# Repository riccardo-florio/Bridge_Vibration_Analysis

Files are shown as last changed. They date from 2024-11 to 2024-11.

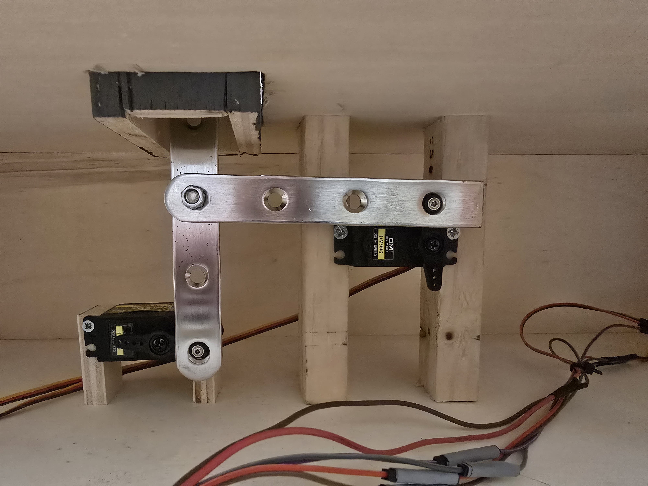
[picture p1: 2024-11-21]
viadotto/immagini e video/meccanismi interni.jpg

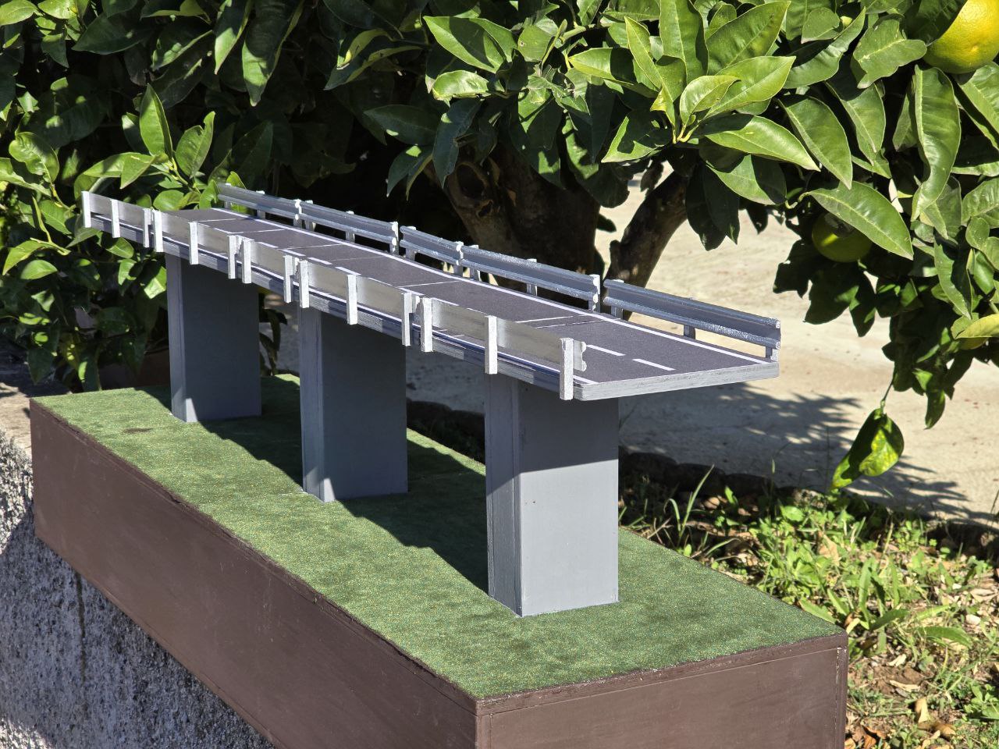
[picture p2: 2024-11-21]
viadotto/immagini e video/pnte completo.jpg

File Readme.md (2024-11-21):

# Bridge_Vibration_Analysis

Questo repository contiene i file e i documenti relativi al progetto di analisi delle vibrazioni di un modello in scala di un ponte. Il progetto è stato ideato per studiare i fenomeni di cedimento strutturale e vibrazioni sismiche, utilizzando sensori inerziali e un'applicazione per la raccolta e analisi dei dati. Condivido questo materiale per rendere il progetto replicabile e utile ad altri ricercatori, studenti e appassionati.

## Descrizione del progetto

Il progetto si basa su un modello in scala di un ponte progettato per simulare due scenari distinti:
1. L'abbassamento di uno o più piloni.
2. Vibrazioni indotte da terremoti.

### Struttura del repository

La repository è organizzata come segue:

- **/docs**: Contiene i documenti di riferimento che spiegano la teoria utilizzata per trasformare i dati dei sensori inerziali in angoli di rollio (roll), beccheggio (pitch) e imbardata (yaw). I documenti disponibili sono:
  - `Raccolta dati da smartphone.docx`: Spiega come raccogliere i dati dai sensori del telefono.
  - `Stima orientamento di un corpo.docx`: Illustra la teoria della stima dell'orientamento.

- **/viadotto**: Contiene i file specifici del modello in scala, suddivisi in sottocartelle:
  - **/codice_arduino**: Include il file `codice_arduino.ino`, fondamentale per il controllo del modello. In questo file sono presenti le variabili che consentono di regolare:
    - **L'abbassamento dei piloni**: *minVertical, maxVertical*.
    - **L'intensità del terremoto**: *minHorizontal, maxHorizontal*.
  - **/immagini e video**: File multimediali che mostrano il modello in funzione.
  - **/modelli 3D**: Contiene i file progettati con SketchUp:
    - `viadotto.skp`: Il modello 3D del ponte.
    - `viadotto abbassato.skp`: Una previsione del comportamento del ponte durante il cedimento di un pilone.
  - **/schema elettrico**: Include lo schema elettrico necessario per replicare il sistema:
    - `Schema elettrico ponte.dwg`
    - `Schema elettrico ponte.pdf`

- **Tesi Riccardo Florio.pdf**: La tesi completa, che documenta ogni aspetto del progetto.

## Obiettivi del progetto

Questo lavoro mira a fornire un sistema replicabile per analizzare le vibrazioni strutturali utilizzando un modello in scala di un ponte. La teoria utilizzata è ben documentata nei file contenuti in `/docs`, mentre le cartelle `/modelli 3D` e `/schema elettrico` offrono tutti i dettagli necessari per costruire il modello fisico. Il file `codice_arduino.ino` consente di controllare i fenomeni simulati, regolando con precisione l'abbassamento dei piloni e l'intensità delle vibrazioni.

## Come usare questo materiale

1. **Studio della teoria**: Inizia leggendo i documenti in `/docs` per comprendere come i dati dei sensori inerziali vengono trasformati in roll, pitch e yaw.
2. **Costruzione del modello**: Usa i file in `/modelli 3D` e `/schema elettrico` per costruire il modello in scala e configurare il sistema elettronico.
3. **Programmazione del modello**: Carica il file `codice_arduino.ino` sulla scheda Arduino Uno e regola le variabili per adattare il comportamento del modello alle tue esigenze.
4. **Simulazione**: Utilizza il modello per simulare scenari di cedimento strutturale e vibrazioni sismiche, raccogliendo dati per analisi successive.

## Licenza

Il materiale condiviso in questa repository è rilasciato con una licenza open-source, consentendo a chiunque di utilizzare, modificare e distribuire i contenuti, con l'obiettivo di promuovere la collaborazione e la condivisione della conoscenza.

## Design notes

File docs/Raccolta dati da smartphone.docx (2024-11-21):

## Introduzione

In questo documento spiego come convertire i dati ricevuti dai sensori inerziali in dati di roll pitch e yaw usando le formule spiegate in “Stima orientamento di un corpo.docx”. Quello che spiego qui è alla base del progetto Sensors To RPY Client (https://github.com/riccardo-florio/Sensors_To_RPY_Client).

## Strumenti utilizzati

App: ServerSensor

Link: https://github.com/umer0586/SensorServer

Altri riferimenti:

- Script python per comunicare con l’app: https://stackoverflow.com/questions/68127440/how-do-i-transmit-real-time-android-sensor-data-to-a-pc-wirelessly
- Per creare l’ambiente virtuale in python: https://www.youtube.com/watch?v=S6LMNLKhaEM&t=470s
- Libreria web: https://github.com/websocket-client/websocket-client

Versione Python: 3.11.3

Editor: PyCharm 2022.2.1

## Procedimento

Innanzitutto, dopo aver installato l’applicazione ServerSensor sul cellulare, ho creato la cartella "sersor_client", l’ho aperta con l’editor e ho creato ed attivato un ambiente virtuale. Quindi, ho selezionato l’interpreter python desiderato (quello della versione 3.11.1).

I dati dei sensori estratti dall’applicazione vengono trasmessi mediante il protocollo WebSocket sotto forma di file json.

In prima istanza creiamo un semplice script python che riceve e mostra a video i dati estratti: uso il codice specificato nella documentazione all’interno nel file "main.py"

Si noti che, affinché tutto funzioni correttamente, deve essere installata la libreria "websocket-client".

Quando tutto funziona, procedo col ricavare le rotazioni di Roll – Pitch – Yaw a partire dai dati estratti dai sensori del cellulare. Un primo codice per estrarre dati di roll e pitch sfruttando l’accelerometro è il seguente:

import websocket
import json
import math

# IP del dispositivo connesso
device_ip = "ws://192.168.1.75:8080"
# Inizializzazione di RPY
roll, pitch, yaw = 0, 0, 0
# Campo magnetico di riferimento

def on_message(ws, message):
# Estrazione dei dati inviati dallo smartphone
values = json.loads(message)['values']
type = json.loads(message)['type']

# Estraggo roll e pitch dall'accelerometro
global roll, pitch, yaw
if type == 'android.sensor.accelerometer':
a_sx = values[0]
a_sy = values[1]
a_sz = values[2]
roll = math.atan2(a_sy, a_sz)
pitch = math.atan2(a_sx, math.sqrt(pow(a_sy, 2) + pow(a_sz, 2)))

if type == 'android.sensor.magnetic_field':
pass

print("roll = ", roll, "pitch = ", pitch, "yaw = ", yaw)


def on_error(ws, error):
print("error occurred")
print(error)


def on_close(ws, close_code, reason):
print("connection close")
print("close code : ", close_code)
print("reason : ", reason)


def on_open(ws):
print("connected")


def connect(url):
ws = websocket.WebSocketApp(url,
on_open=on_open,
on_message=on_message,
on_error=on_error,
on_close=on_close)

ws.run_forever()


connect(device_ip + '/sensors/connect?types=[' +
'"android.sensor.accelerometer",' +
'"android.sensor.gyroscope",' +
'"android.sensor.magnetic_field"]')

Per ricavare pitch dobbiamo sfruttare il magnetometro. Oltre ai dati da esso estratti, sono necessari i dati del sistema di riferimento globale. Li ricaviamo dal sito indicato di seguito inserendo latitudine e longitudine della zona in cui si trova il sensore, oppure inserendo il cap.

https://www.ngdc.noaa.gov/geomag/calculators/magcalc.shtml#igrfwmm

Ottenuti i dati dell’ENU, li converto in microtesla e li memorizzo:

A questo punto applico le formule e calcolo YAW:

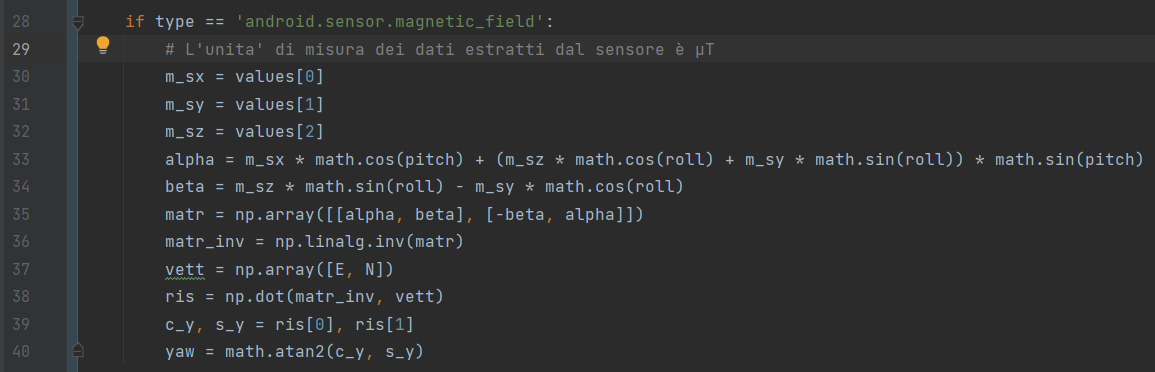
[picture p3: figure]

## Grafico real – time di RPY

Per questo scopo usiamo la libreria "matplotlib". Implementiamo un meccanismo per cui ogni secondo viene aggiornato il grafico con i nuovi valori rilevati dai sensori. Il problema incontrato in questa fase è che, per poter rilevare i dati dai sensori e contemporaneamente graficarli, bisogna eseguire due funzioni, "connect(…)" e "plt.show", in maniera concorrente. Eseguiamo la prima in un thread separato da quello principale.

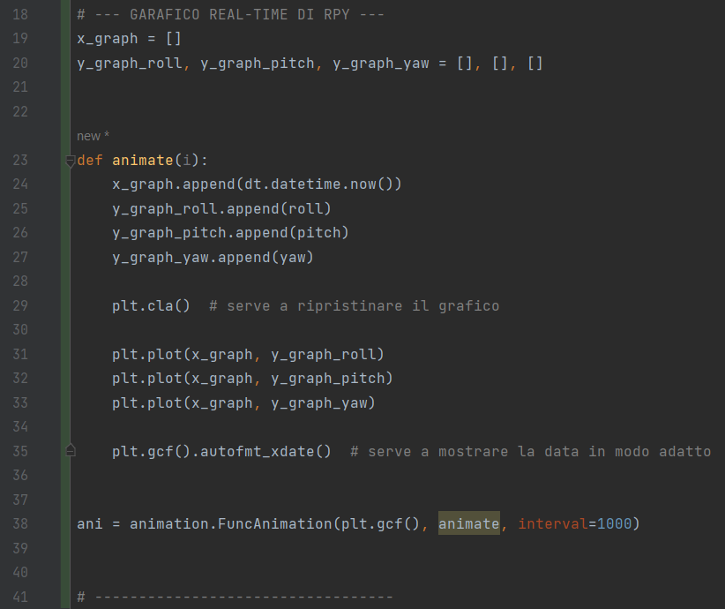
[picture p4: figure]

Di seguito, il codice per eseguire il rilevamento dei dati in un thread secondario:

## Applicazione del filtro

A questo punto possiamo notare come i dati dei sensori siano abbastanza rumorosi. Possiamo filtrarli con il seguente filtro passa – basso:

r(k)=α⋅r(k-1)+(1-α)⋅r_(acc) (k)

Dove:

- r(k) è il valore filtrato al tempo k
- r(k-1) è il valore filtrato al tempo precedente.
- r_(acc) (k) è il valore attuale del segnale (ad esempio, roll, pitch o yaw).
- α è un coefficiente che determina il grado di smussamento.

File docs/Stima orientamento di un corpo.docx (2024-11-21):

## Stima dell’orientamento di un dispositivo

(Fonte: materiale Professore)

L’orientamento di un corpo rigido può essere definito sia nello spazio tridimensionale, ovvero in R^3 , che su un piano bidimensionale, ovvero in R^2 .

Due corpi possono condividere la stessa posizione ma differire nell’orientamento; pertanto, è fondamentale comprendere come valutare l’orientamento di un corpo per determinarne lo stato.

### Stima dell’orientamento

Per stimare l’orientamento di un corpo sul piano, è richiesta una variabile reale θ∈R .

Per stimare l’orientamento di un corpo nello spazio, invece, sono necessarie tre variabili a valori reali ϕ∈R, ψ∈R, θ∈R .

Ci concentreremo, nel seguito, sull’orientamento in R^3

In particolare, è possibile raggiungere qualsiasi orientamento target partendo da un orientamento di riferimento noto, mediante l’applicazione di una sequenza specifica di rotazioni, le cui grandezze sono gli angoli di rotazione dell’orientamento del target.

3 angoli opportunamente scelti definiscono in modo inequivocabile l’atteggiamento di un corpo, ma dato un corpo, ci sono diversi gruppi di 3 angoli (opportunamente scelti) che ne definiscono l’orientamento.

### Orientamento di un corpo

Da un punto di vista generale, definire l’orientamento di un corpo implica stabilire l’orientamento di un sistema di riferimento attaccato al corpo {O’, x’, y’, z’} in relazione a un sistema di riferimento di interesse {O, x, y, z}

Da un punto di vista formale, ci sono tre modi principali per definire l’orientamento di un corpo:

- Matrici di rotazione
- Angoli di Eulero
- Quaternioni

Scegliere il formalismo appropriato rappresenta uno dei task principali in un sistema di posizionamento.

#### Matrici di rotazione

Le matrici rotazionali, spesso denominate matrici direzione coseno (DCMs), descrivono come un sistema di riferimento attaccato al corpo è orientato rispetto a un altro sistema di riferimento di interesse, in R^3 o in R^2 .

Funzionamento in R^2

Consideriamo due sistemi di riferimento A={O, x,y,z} e B={O, x^(') ,y^(') ,z^(') } , entrambi centrati nello stesso punto, ma con il secondo ruotato di un angolo α rispetto al primo.

Sia P un punto espresso come P_1 =(p_x , p_y ) in riferimento ad A e come P_2 =(p^(') _x , p^(') _y ) in riferimento a B.

Il punto P2 può essere referenziato rispetto al sistema di riferimento A:

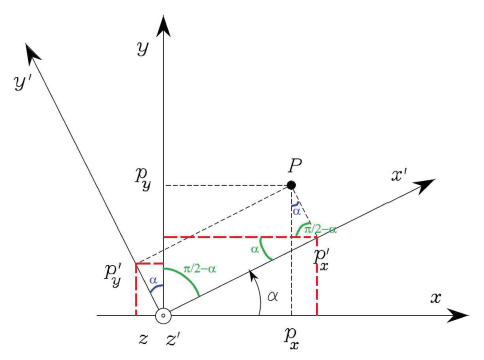
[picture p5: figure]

Ovvero:
p_x =p_x^(') cosα-p_y^(') sinα p_y =p_x^(') sinα+p_y^(') cosα
In forma matriciale:
P_1 =[cosα, -sinαsinα, cosα]
Matrice di rotazione:
R(α)=RB→A=[cosα, -sinαsinα, cosα] (ruota un punto in B in un punto in A)
Proprietà di R(α) :

1) RA→B=R^(-1) B→A=R^T B→A , cioè RA→B è una matrice ortogonale
2) R(-α)=R^T (α)
3) det{R(α)}=1
4) Le colonne di R(α) sono i versori che definiscono una base per B, espressa nel sistema di riferimento A. In altre parole, R(α) è una matrice di cambiamento di base, da B ad A.
5) R(α(t))=α(t)[0, -11, 0]R(α(t))

Funzionamento in R^n

Una matrice di rotazione R è tale che R∈SO(n) , dove SO(n) è il particolare gruppo ortogonale di matrici reali in R^(n×n) , cioè:

SO(n)={M∈R^(n×n) t.c. MM^T =M^T M=I_n ∧det{M}=1}

Proprietà:

1) RA→B=R^(-1) B→A=R^T B→A
2) det{R}=1
3) Ogni matrice R∈SO(n) è una matrice dei coseni direttori (vedi più avanti)
4) A causa del vincolo RR^T =R^T R=I_n , nonostante R abbia n^2 voci, solo (n(n-1))/2 parametri liberi sono ammessi; le n^2 voci sono funzioni di tali parametri liberi. In particolare: n=2→1 parametro libero n=3→3 parametri liberi
5) R(t)=A(t)R(t) , dove A(t)∈R^(n×n) è tale che A(t)+A^T (t)=0_(n×n) , cioè A(t) è una matrice antisimmetrica (vedi dopo).
6) R(t)=Φ[t,t_0 ]R(t_0 ) , dove Φ[t,t_0 ]∈R^(3×3) è una funzione tempo – variante. Inoltre, se R(t) è una rotazione tempo – variante con velocità costante, allora:

R(t)=e^(A(t-t_0 )) R(t_0 )

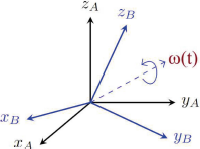
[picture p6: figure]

7) Considerando due sistemi di riferimento: A fisso e B che ruota intorno ad A con velocità ω(t)∈R^3 , dove:
  a. (ω(t))/(‖ω(t)‖) è l’asse di rotazione
  b. ‖ω(t)‖ è la velocità di rotazione attorno a ω(t)
  c. ω_A (t) e ω_B (t) definiscono ω(t) in A e in B rispettivamente

Allora, saranno soddisfatte le seguenti relazioni:

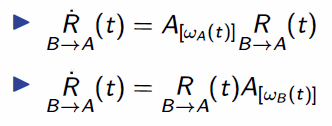
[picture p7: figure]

Ricorda queste ultime formule perché serviranno nello studio dei quaternioni in relazione alla velocità angolare.

L’operatore antisimmetrico

Analizziamo il caso di n=3

Sia v∈R^3 =[v_x ,v_y ,v_z ]^T , allora l’operatore antisimmetrico è A_([v]) , definito come:

L’operatore antisimmetrico rappresenta un prodotto incrociato:

Rotazione e traslazione

Consideriamo due sistemi di riferimento:

- A = {O_A ,x_A ,y_A ,z_A }
- B = {O_B ,x_B ,y_B ,z_B }

In cui O_B è rappresentato dal vettore t∈R^3 nel sistema di riferimento A.

Un punto P∈R^3 in A si indica con:

P_A =RB→AP_B +t

Oppure, in forma matriciale:

[, P_A , 1]=[RB→A, t0_3^T , 1][, P_B , 1]=R_t B→A[, P_B , 1]

R_t B→A∈R^(4×4) è una matrice di trasformazione e R_t B→A^(-1) =[RB→A^T , -RB→A^T t0_3^T , 1]

Matrice dei coseni direttori

(Fonte: D. Titterton, J. Weston, Strapdown Inertial Navigation Technology, Peter Peregrinus Ltd, 1997) (Ho praticamente copiato il paragrafo dal libro)

Un generico vettore V, riferito ad una terna cartesiana (a) di assi x, y, z, può essere definito come la somma di tre vettori:

V_a = V_x + V_y + V_z = V_x i + V_y j + V_z k

dove ciascuno dei termini rappresenta il vettore ottenuto proiettando V_a sugli assi della terna (a) di versori i, j, k.

Lo stesso vettore, riferito ad una seconda terna (b) avente la stessa origine e di assi x', y', z', può essere rappresentato in modo analogo dall'espressione:

V_b = V_(x^(')) + V_(y^(')) + V_(z^(')) = V_(x^(')) i^(') + V_(y^(')) j^(') + V_(z^(')) k^(')

dove ciascuno dei tre termini può essere ottenuto proiettando V_x , V_y , V_z rispettivamente sugli assi x', y', z' della terna (b) di versori i', j', k'.

Si ha pertanto:

V_(x^(')) = [V_x cos(x^(') ,x); V_y cos(x^(') ,y); V_z cos(x^(') ,z)]

V_(y^(')) = [V_x cos(y^(') ,x); V_y cos(y^(') ,y); V_z cos(y^(') ,z)]

V_(z^(')) = [V_x cos(z^(') ,x); V_y cos(z^(') ,y); V_z cos(z^(') ,z)]

dove, per esempio, cos(x^(') ,y) rappresenta il coseno dell'angolo che l'asse x' della terna (b) forma con l'asse y della terna (a) ed è indicato come coseno direttore.

Si può anche scrivere:

V_(x^(')) = [C_11 V_x ; C_12 V_y ; C_13 V_z ]

V_(y^(')) = [C_21 V_x ; C_22 V_y ; C_23 V_z ]

V_(z^(')) = [C_31 V_x ; C_32 V_y ; C_33 V_z ]

o, più sinteticamente:

V_b = C_a^b V_a

dove C_a^b è la matrice dei cosenti direttori che ci permette di passare dalla terna (a) alla terna (b):

C_a^b =(C_11 , C_12 , C_13 C_21 , C_22 , C_23 C_31 , C_32 , C_33 )

L'elemento C_(ij) della matrice C_a^b rappresenta, quindi, il coseno che l'asse i della terna (b) forma con l'asse j della terna (a).

Il passaggio da una terna all'altra può avvenire anche attraverso una o più terne intermedie come, ad esempio:

V_b = C_c^b C_a^c V_a

Il prodotto delle matrici non è commutativo, pertanto:

C_c^b C_a^c ≠ C_a^c C_c^b

Se le due terne sono ortogonali, l'inversa della matrice è uguale alla sua trasposta e si ha:

C_a^b = (C_a^b )^(-1) = (C_a^b )^T

avendo indicato con l'apice T la trasposta.

La stessa matrice può anche essere ottenuta tenendo presente che è possibile passare dalla terna (a) alla terna (b) mediante tre successive rotazioni θ_1 ,θ_2 ,θ_3 rispetto a ciascun asse.

Per esempio, la rotazione intorno all’asse z di un angolo θ_3 , indicata con R_z (θ_3 ) , lascia invariata la direzione dell’asse z mentre gli assi x, y (e quindi i versori i, j) ruotano di un angolo θ_3 . Si ha, per la relazione x^(') =cos(θ)x +sin(θ)(e×x) , che:

i_1 =cosθ_3 i+sinθ_3 j

j_1 =-sinθ_3 i+cosθ_3 j

k_1 =k

O più sinteticamente

(i_1 j_1 k_1 )=(cosθ_3 , sinθ_3 , 0-sinθ_3 , cosθ_3 , 00, 0, 1)(ijk)

Pertanto:

R_z (θ_3 )=(cosθ_3 , sinθ_3 , 0-sinθ_3 , cosθ_3 , 00, 0, 1)

Analogamente, una rotazione di un angolo θ_1 intorno all’asse x ed una rotazione di un angolo θ_2 intorno all’asse y si possono rappresentare rispettivamente con le matrici:

R_x (θ_1 )=(1, 0, 00, cosθ_1 , sinθ_1 0, -sinθ_1 , cosθ_1 ) R_y (θ_2 )=(cosθ_2 , 0, -sinθ_2 0, 1, 0sinθ_2 , 0, cosθ_2 )

Gli angoli θ_1 ,θ_2 ,θ_3 vengono detti angoli di Eulero.

La matrice dei coseni direttori C_a^b può ricavarsi effettuando il prodotto delle tre matrici ora definite nell’ipotesi di conoscere gli angoli di rotazione e la successione di essi in quanto il prodotto delle matrici non è commutativo.

(Fine matrice dei coseni direttori – libro “Navigazione inerziale e integrata”)

#### Angoli di Eulero

Immaginiamo di prendere il frame (= sistema di riferimento) A in mano e di ruotarlo finché non appare proprio come il frame B. Il teorema di rotazione di Eulero afferma che qualsiasi rotazione può essere considerata come una sequenza di rotazioni attorno a diversi assi di coordinate.

Teorema di rotazione di Eulero

Due sistemi di coordinate ortonormali indipendenti possono essere collegati da una sequenza di rotazioni (non più di tre) attorno agli assi di coordinate, dove non ci possono essere due rotazioni successive attorno allo stesso asse.

Rotazioni elementari (standard)

Una rotazione elementare è una rotazione intorno ad un asse (x, y o z) che coinvolge solo un angolo, cioè l’angolo di rotazione attorno all’asse scelto.

- Rotazione attorno all’asse x (primo asse): R_x (θ_1 )=(1, 0, 00, cosθ_1 , sinθ_1 0, -sinθ_1 , cosθ_1 )
- Rotazione attorno all’asse y (secondo asse): R_y (θ_2 )=(cosθ_2 , 0, -sinθ_2 0, 1, 0sinθ_2 , 0, cosθ_2 )
- Rotazione attorno all’asse z (terzo asse): R_z (θ_3 )=(cosθ_3 , sinθ_3 , 0-sinθ_3 , cosθ_3 , 00, 0, 1)

Una generica matrice di rotazione può essere ottenuta componendo un'opportuna sequenza di tre rotazioni elementari, garantendo che non vengano effettuate due rotazioni successive attorno ad assi paralleli.

La rotazione finale dipende dall'ordine in cui vengono applicate le rotazioni.

Si noti che le rotazioni non sono commutative in R^3 : ruotando attorno a X di π/2 e poi attorno ad Y di π/2 porta ad un risultato diverso rispetto ad una rotazione attorno all’asse Y di π/2 e poi attorno all’asse X di π/2 .

Esistono due classi di sequenze di rotazione: le rotazioni di Eulero e le rotazioni di Cardano.

Rotazioni di Eulero

Implicano la ripetizione, ma non successiva, di rotazioni attorno ad un asse particolare.

Sei triplette di angoli: XYX, XZX, YXY, YZY, ZXZ, ZYZ

Rotazioni di Cardano

Sono caratterizzati da rotazioni attorno a tutti e tre gli assi.

Sei triplette di angoli: XYZ, XZY, YZX, YXZ, ZXY, ZYX

Nell'uso comune tutte queste sequenze sono chiamate Angoli di Eulero e, attenzione, ce ne sono un totale di 12 tra cui scegliere.

Rotazioni Estrinseche ed Intrinseche

Dato l'insieme delle rotazioni elementari da compiere, come devono essere composte queste rotazioni per ottenere la matrice di rotazione completa?

La domanda che sorge è se la seconda, la terza, … rotazioni si riferiscono tutte al nostro sistema di coordinate globale (estrinseco) o all'ultimo sistema di coordinate ruotato (intrinseco).

Esistono due modi possibili per ruotare:

1) Rotazioni intrinseche: le tre rotazioni elementari sono gli assi del sistema di coordinate rotante solidale con il corpo in movimento, che cambia la sua orientazione dopo ogni rotazione elementare.
2) Rotazioni estrinseche: le tre rotazioni elementari riguardano gli assi xyz del sistema di coordinate originale, che si assume rimanga immobile.

Si può dimostrare che eseguire una sequenza di tre rotazioni intrinseche equivale ad eseguire la sequenza INVERSA di rotazioni estrinseche.

COME SUGGERIMENTO PRINCIPALE: NON PENSARE AI SISTEMI DI RIFERIMENTO ROTANTI MA PENSARE A COME RUOTANO I VETTORI.

In altre parole, se si ha un vettore v_3 ∈R^3 ed espresso nel sistema di riferimento O, x_3 , y_3 , z_3 che si vuole esprimere in O, x_0 , y_0 , z_0 passando attraverso la sequenza di rotazioni (solitamente rotazioni standard) O, x_2 , y_2 , z_2 e O, x_1 , y_1 , z_1 quindi

v_0 =[R1→0]v_1 =[R1→0][R2→1]v_2 =[R1→0][R2→1][R3→2]v_3

Ne segue che, indipendentemente dalle rotazioni estrinseche ed intrinseche,

[R3→0]=[R1→0][R2→1][R3→2]

Roll – Pitch – Yaw

Roll-Pitch-Yaw sono probabilmente le triplette di angoli di Eulero più famose.

Intrinseche:

1) Rotazione intorno a x di roll
2) Rotazione attorno a y’ di pitch
3) Rotazione attorno a z’’ di yaw

R(r,p,y)=R_x (r)R_y (p)R_z (y)

Estrinseche:

1) Rotazione attorno a z di yaw
2) Rotazione attorno a y di pitch
3) Rotazione attorno a x di roll

R(r,p,y)=R_x (r)R_y (p)R_z (y)

R(r,p,y)=(1, 0, 00, cosr, sinr0, -sinr, cosr)(cosp, 0, -sinp0, 1, 0sinp, 0, cosp)(cosy, siny, 0-siny, cosy, 00, 0, 1)

Questa matrice va dal frame fisso a quello rotante.

Per ottenere r, p, y da R, ci sono due possibili soluzioni:

y=arctan_2 ((R_12)/(R_11)) p=arctan_2 ((-R_13)/(√(R_23^2 +R_33^2))) r=arctan_2 ((R_23)/(R_33)) In questo caso p∈[-π/2,π/2] | y=arctan_2 ((-R_12)/(-R_11)) p=arctan_2 ((-R_13)/(-√(R_23^2 +R_33^2))) r=arctan_2 ((-R_23)/(-R_33)) In questo caso p∈[π/2,(3π)/2]

Blocco cardanico

Un problema fondamentale con le rappresentazioni a tre angoli sono le singolarità.

Una singolarità si verifica quando l’asse di rotazione del temine medio della sequenza diventa parallelo all’asse di rotazione del primo o del terzo termine.

La singolarità più famosa negli angoli di Eulero è il blocco cardanico. Il blocco del giunto cardanico è la perdita di un grado di libertà in un meccanismo tridimensionale a tre giunti cardanici che si verifica quando gli assi di due dei tre giunti cardanici vengono guidati in una configurazione parallela, bloccando il sistema in rotazione in uno spazio bidimensionale degenerato.

Si consideri la situazione in cui l'angolo di rotazione dell’asse centrale è di 90 gradi; allora gli assi interno ed esterno sono allineati e condividono lo stesso asse di rotazione. Invece dei tre assi di rotazione originali, poiché due sono paralleli, ora ci sono solo due assi di rotazione effettivi. Un grado di libertà è andato perduto!

Da un punto di vista matematico, nel caso di RPY, il blocco cardanico avviene quando pitch=π/2

R(r,π/2,y)=(0, 0, -1sin(r-y), cos(r-y), 0cos(r-y), -sin(r-y), 0)

Il che significa che cambiando roll o yaw si ottiene una rotazione lungo lo stesso asse. Abbiamo 3 angoli ma solo due gradi di libertà.

Le singolarità non possono essere evitate. Il meglio che si possa sperare è che la singolarità si verifichi per un orientamento che non si verifica durante il normale funzionamento del veicolo. Le singolarità sono una conseguenza dell'uso di una rappresentazione minima. Per eliminare questo problema, è necessario adottare una diversa rappresentazione dell'orientamento. Per questo motivo studieremo i QUATERNIONI.

Derivata temporale di RPY

L'obiettivo è ottenere la derivata temporale degli angoli r, p e y rispetto alla velocità di rotazione ω_(rot) (t) nel sistema di riferimento rotante.

Considerando R=R_x (r)R_y (p)R_z (y) e guardando l’ordine delle matrici

1) La prima matrice esprime una rotazione attorno a z di un angolo y con una velocità y . La velocità di rotazione è [0, 0, y]^T e nel sistema rotante si esprime come:

ω_(rot,1) =R_x (r)R_y (p)[00y]

2) La seconda matrice esprima una rotazione attorno a y di un angolo p con una velocità p . La velocità di rotazione è [0, p, 0]^T e nel sistema rotante si esprime come:

ω_(rot,2) =R_x (r)[0p0]

3) La seconda matrice esprima una rotazione attorno a x di un angolo r con una velocità r . La velocità di rotazione è [r,0 , 0]^T e nel sistema rotante si esprime come:

ω_(rot,3) =[r,0 , 0]^T

La velocità complessiva del sistema rotante sarà quindi:

ω_(rot) (t)=ω_(rot,1) (t)+ω_(rot,2) (t)+ω_(rot,3) (t)=[[100]TODO][rpy]

Che può essere scritta come:

ω_(rot) (t)=Ω[rpy]

Equazioni di giunto cardanico:

[rpy]=Ω^(-1) ω_(rot) (t)=[1, sin(r)tan(p), cos(r)tan(p)0, cos(r), -sin(r)0, (sin(r))/(cos(p)), (cos(r))/(cos(p))]ω_(rot) (t)

RPY da accelerometro e magnetometro

Ricaviamo roll e pitch da accelerometro, mentre yaw dal magnetometro.

Consideriamo che:

1. gli assi dei sensori siano allineati
2. il sistema di riferimento xyz sia centrato su tali assi (sistema di riferimento del sensore)
3. il sistema di riferimento globale sia l’ENU (si veda più avanti)

Descrivendo l’orientamento del sensore rispetto all’ENU mediante:

Renu→s=R_x (r)R_y (p)R_z (y)

Roll e pitch (assumendo p∈[-π/2,π/2] ) si ottengono come segue:

a_s =Renu→sa_(enu) =Renu→s[00-g]=[sin(p)-cos(p)sin(r)-cos(p)cos(r)]=[a_(s,x) a_(s,y) a_(s,z) ]

r=arctan_2 ((a_(s,y))/(a_(s,z)))

p=arctan_2 ((a_(s,x))/(√(a_(s,y)^2 +a_(s,z)^2)))

Dove a_(s,x) ,a_(s,y) ,a_(s,z) sono i dati estratti dall’acceletometro

Sia m_0 ∈R^3 il campo magnetico di riferimento, nel sistema di riferimento ENU, nella posizione di interesse, e m_s ∈R^3 il campo magnetico misurato nel sistema di riferimento del sensore. Siano s_θ , c_θ rispettivamente sin(θ),cos(θ) . Yaw si ottiene come segue:

yaw=arctan_2 ((s_y)/(c_y))

Dove:

m_(0,x) =[m_(s,x) c_p +(m_(s,z) c_r +m_(s,y) s_r )s_p ]c_y +[m_(s,z) s_r -m_(s,y) c_r ]s_y

m_(0,y) =[-m_(s,z) s_r +m_(s,y) c_r ]c_y +[m_(s,x) c_p +(m_(s,z) c_r +m_(s,y) s_r )s_p ]s_y

m_(0,x) =αc_y +βs_y

m_(0,y) =-βc_y +αs_y

[, c_y , s_y ]=[α, β-β, α]^(-1) [, m_(0.x) , m_(0.y) ]

Nota principale: le equazioni che forniscono rpy a partire dall'accelerometro e dal magnetometro possono essere utilizzate come equazioni di output in un processo di fusione dei sensori in cui le equazioni di giunto cardanico vengono utilizzate per il modello.

### Quaternioni

Sono vettori di quattro dimensioni, cioè q∈R^4 .

Un quaternione è un numero ipercomplesso, che è un concetto matematico che estende l’idea di numero complesso a quattro dimensioni. Si rappresenta come:

q=s+v_1 i+v_2 j+v_3 k=s<v> =(s)<v>

Dove:

- s∈R è la parte scalare reale. Re[q]=s
- v=[v_1 ,v_2 ,v_3 ]^T ∈R^3 è la parte immaginaria rispettivamente lungo le unità immaginarie i, j, e k. Im[q]=v

I vettori base soddisfano le seguenti relazioni:

i^2 =j^2 =k^2 =ijk=-1; ij=-ji=k; jk=-kj=i; ki=-ik=j

( 1. 1 )

I quaternioni offrono un modo compatto ed efficiente per rappresentare rotazioni in R^3 , evitando alcuni inconvenienti associati agli angoli di Eulero.

Operazioni con i quaternioni

Siano q=s<v> , p=r<w> , allora:

- SOMMA: q+p=(s+r)<v+w>
- NORMA: ‖q‖=|q|=√(s^2 +v^T v)=√(s^2 +v_1^2 +v_2^2 +v_3^2)
- CONIUGATO: q^(*) =s<-v>
- PRODOTTO: q∘p=(sr-v^T w)<sw+rv+v×w> , che si può scrivere sotto forma di matrice come:

q∘p=[s, -v^T v, sI_3 +A_([v]) ][rw]=[r, -w^T w, rI_3 -A_([w]) ][sv]

Dove l’operatore antisimmetrico è A_([v]) =[0, -v_3 , v_2 v_3 , 0, -v_1 -v_2 , v_1 , 0]

(Fonte del pezzo seguente: D. Titterton, J. Weston, Strapdown Inertial Navigation Technology, Peter Peregrinus Ltd, 1997, paragrafo 3,6)

Due quaternioni sono uguali soltanto se tutti i loro componenti sono uguali; la somma (o la differenza) di due quaternioni si esegue come se questi fossero due polinomi, sommando (o sottraendo) i termini simili. Analogamente il prodotto di due quaternioni si esegue come un ordinario prodotto di polinomi tenendo presente la relazione (1.1). Il prodotto tra quaternioni non è commutativo

Alcune proprietà e definizioni

Siano q=s<v>, p=r<w> , allora:

- q∘q^(*) =[s, -v^T v, sI_3 +A_([v]) ][, s, -v]=[, s^2 +v^T v, vs-sv+v×(-v)]=[, ‖q‖^2 , 0_3 ]
- ‖q∘p‖^2 =‖q‖^2 ‖p‖^2
- (q∘p)^(*) =p^(*) ∘q^(*)
- Dato un vettore x∈R^3 , il quaternione associato è x_q =0<x> , cioè un quaternione con Re[x_q ]=0 e Im[x_q ]=x
- q^T p=sr+v^T w
- q∘p≠p∘q
- Considerando un terzo quaternione m , q∘p∘m=(q∘p)∘m=q∘(p∘m)

Quaternioni come rotazioni

Consideriamo il sottoinsieme dei quaternioni unitari Q_U ={q∈R^4 t.c. ‖q‖=1} .

Tutti i quaternioni in Q_U possono essere scritti come:

q=cos(ϕ/2)<sin(ϕ/2)n>con ‖n‖=1

Dati x∈R^3 e q=cos(ϕ/2)<sin(ϕ/2)n> , cos’è x_q^(') =q^(*) ∘x_q ∘q ?

Svolgendo alcuni calcoli otteniamo che:

Analizzando separatamente le due parti ricaviamo che:

Re[q∘q]=…=0

Im[q∘q]=…=

Ancora non sappiamo classificare x' ma vedrai subito dopo che rappresenta la rotazione del vettore x attorno ad un determinato asse.

Punto di vista geometrico

Consideriamo un piano ortogonale ad n e passante attraverso x .

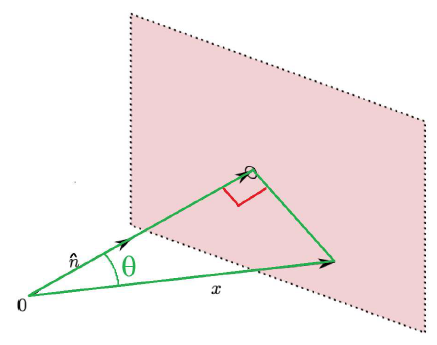
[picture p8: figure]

Il vettore λn che è diretto lungo n e tocca il piano è la proiezione di x su n . Considerando il triangolo rettangolo verde e ‖n‖=1 :

‖λn‖=λ=‖x‖cos(θ)=‖x‖‖n‖cos(θ)=

=x^T n

E quindi il vettore diretto lungo n e che tocca il piano è:

(x^T n)n

Consideriamo ora il vettore v_1 =x-(x^T n)n :

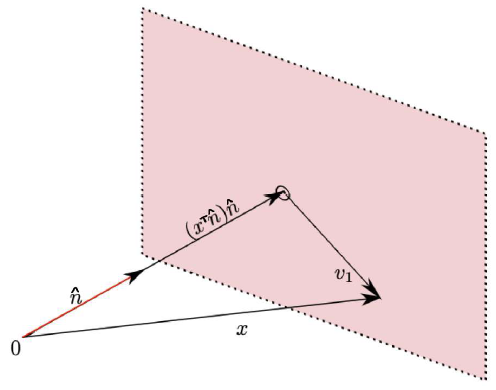
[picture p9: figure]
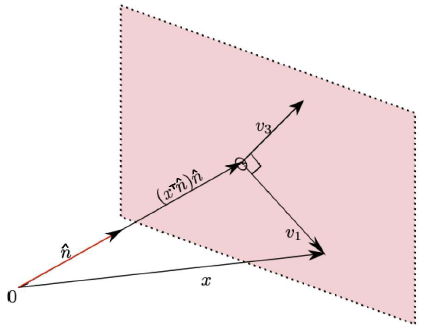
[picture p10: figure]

E il vettore v_3 tale che v_3 ⊥v_1 e v_3 ⊥n :

v_3 =v_1 ×n

e

‖v_3 ‖=‖v_1 ‖‖n‖sin(π/2)=‖v_1 ‖

Così come v_3 è sul piano ortogonale ad n :

v_3^T n=(v_2 ×n)^T n=0

Dato che v_3 è ortogonale ad n per definizione.

I vettori v_1 e v_3 sono una base per il piano ortogonale a n .

Consideriamo ora il vettore v_2 , corrispondente al vettore v_1 ruotato di un angolo ϕ intorno a n :

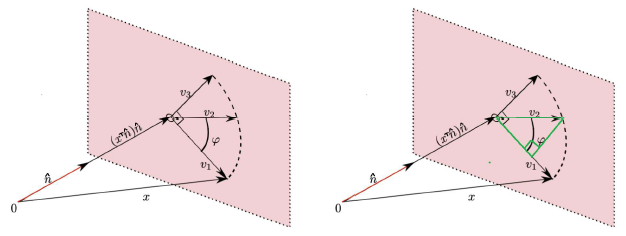
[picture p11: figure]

‖v_2 ‖=‖v_1 ‖

v_2 =v_2^(∥) +v_2^(⊥)

Dove:

- v_2^(∥) è la componente di v_2 parallela a v_1
- v_2^(⊥) è la componente di v_2 ortogonale a v_1 , cioè la componente parallela a v_3

v_2^(∥) =‖v_2 ‖cos(ϕ)(v_1)/(‖v_1 ‖)=v_1 cos(ϕ) , v_2^(⊥) =‖v_2 ‖sin(ϕ)(v_3)/(‖v_3 ‖)=v_3 sin(ϕ)

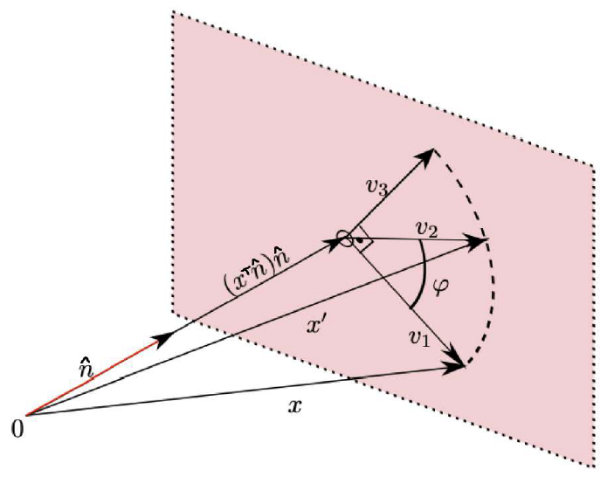
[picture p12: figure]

Consideriamo ora il vettore x^(') =(x^T n)n+v_2 , ovvero il vettore x ruotato di un angolo ϕ attorno all’asse n .

Sviluppando i calcoli, risulta che:

x^(') =(x^T n)n+v_2 =…=Im[q^(*) ∘x_q ∘q]

ovvero la parte immaginaria di q^(*) ∘x_q ∘q è la versione ruotata di x attorno all’asse n di un angolo ϕ .

Quindi, un quaternione unitario rappresenta una rotazione

Rotazioni di interesse

1. Rotazione nulla:

se ϕ=0 allora il quaternione unitario è q_0 =1<0_3 > e quindi:

x^(') =Im[q_0^(*) ∘x_q ∘q_0 ]=…=x

q_0 è il quaternione nullo in termini di rotazioni

2. Rotazione inversa:

partendo da x_q^(') =q^(*) ∘x_q ∘q e moltiplicando per q^(*) e per q entrambi i membri ottengo, dopo una serie di passaggi, che: q∘x_q^(') ∘q^(*) =x_q

Quaternioni e velocità angolare

Consideriamo due sistemi di riferimento: A fisso e B che ruota rispetto ad A con velocità ω(t)∈R^3 , dove:

- (ω(t))/(‖ω(t)‖) è l’asse di rotazione
- ‖ω(t)‖ è la velocità di rotazione attorno a ω(t)
- ω_A (t) e ω_B (t) definiscono ω(t) in A e in B rispettivamente

Sia x un vettore e x_A , x_B la rappresentazione di questo vettore rispettivamente in A e in B.

Si noti che, dato che B ruota mentre A è fermo, allora x_B è fisso ( x_B =0_3 ) mentre x_A si muove.

Poiché stiamo considerando una rotazione, esiste un quaternione unitario q tale che:

- x_(A,q) =q∘x_(B,q) ∘q^(*)
- x_(B,q) =q^(*) ∘x_(A,q) ∘q

Iniziando da x_(A,q) =q∘x_(B,q) ∘q^(*) , la derivata temporale risulta essere:

x_(A,q) =q∘x_(B,q) ∘q^(*) +q∘x_(B,q) ∘q^(*) +q∘x_(B,q) ∘q^(*) =…=q∘q^(*) ∘x_(A,q) +x_(A,q) ∘q∘q^(*)

Concentriamoci ora su q∘q^(*) e q∘q^(*) . Sviluppando alcuni calcoli risulta che:

- q∘q^(*) =0<v>
- q∘q^(*) =0<-v>

Con v=q_R q_I -q_R q_I +q_I ×q_I

q_R , q_I , q_R , q_I sono rispettivamente le parti reali e immaginarie di q e q .

Otteniamo quindi:

x_(A,q) =…=0<2(v×x_A )>

x_A e x_B sono legati dalla rotazione x_A =RA→Bx_B , quindi:

x_A =RA→Bx_B +RA→Bx_B =RA→Bx_B

Ricordando che:

Allora:

x_A =A_([ω_A ]) RB→Ax_B =A_([ω_A ]) x_A =ω_A ×x_A

(Se qui non ti torna qualche passaggio, rivedi "orientamento di un corpo -> matrici di rotazione -> funzionamento in R^n -> proprietà").

A questo punto, paragonando il risultato ottenuto con x_(A,q) =0<2(v×x_A )> , risulta che:

x_A =Im[x_(A,q) ]=2(v×x_A )=2v×x_A =ω_A ×x_A

ω_A =2_V

ω_(A,q) =2q∘q^(*)

Moltiplicando ambo i lati per q :

q=1/2ω_(A,q) ∘q

Seguendo lo stesso procedimento, possiamo ricavare che:

q=1/2q∘ω_(B,q)

Quaternioni e velocità angolari: forma matriciale

Siano Im[q]=[q_1 ,q_2 ,q_3 ]^T , Im[q]=[q_1 ,q_2 ,q_3 ]^T , allora:

ω_(A,q) =2q∘q^(*) =0<Eq>

Con: E=[-q_1 , , , , , ,

## Studio sensori inerziali

Sensori locali

I sensori locali forniscono informazioni che non sono legate al valore dello stato (posizione) ma al valore delle relative variazioni di stato (velocità). Questi sensori svolgono un ruolo cruciale nell'analisi del movimento e nei sistemi di tracciamento, fornendo informazioni sui movimenti locali di utenti, oggetti e veicoli. Di solito forniscono un'informazione differenziale, non legata alla posizione dell'utente ma al movimento relativo dell'utente. I sensori locali comuni includono accelerometri e giroscopi.

Nell'attività di fusione dei sensori questi sensori vengono, nella maggior parte dei casi, utilizzati per definire l'equazione basata sulla transizione:

x_(k+1) =f(x_k ,u_k )+w_k

Consideriamo un punto cinematico che si muove in R^2 come:

x_(k+1) =x_k +T_s v_k , x_k ∈R^2

E supponiamo di avere un sensore di velocità capace di misurare v_k in ogni istante di tempo k .

Integrando la velocità misurata, il percorso risultante è ottenuto solo in termini di movimento relativo.

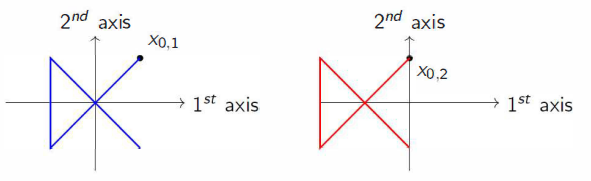
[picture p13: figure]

Serve una stima della condizione iniziale di x_0 .

Sensori globali

I sensori globali forniscono informazioni strettamente correlate al valore dello stato (posizione). Raccolgono dati da un'ampia area geografica o in tutto il mondo. Misure tipiche sono: posizione geografica, informazioni temporali, dati ambientali, ecc.…

Esempi di sensori globali sono: GNSS, wi-fi, reti cellulari, …

Nell'attività di fusione dei sensori questi sensori vengono, solitamente, utilizzati per definire l'equazione di uscita:

y_k =g(x_k ,u_k )+v_k

### Accelerometro

È uno strumento che misura l’accelerazione corretta. L’accelerazione corretta indica l’accelerazione (il tasso di variazione della velocità) di un corpo nel suo sistema di riposo istantaneo; ciò è diverso dall’accelerazione delle coordinate, che è l’accelerazione in un sistema di coordinate fisso. Ad esempio, un accelerometro fermo sulla superficie della Terra misura un’accelerazione dovuta alla gravità terrestre, diretta verso l’alto (per definizione) di g≈9.81m/(s^2) . Al contrario, un accelerometro in caduta libera (che cadono verso il centro della Terra con un’accelerazione di circa 9.81m/(s^2) ) misurerà zero.

L'accelerometro misura l'accelerazione che agisce sul sensore stesso.

#### Meccanica

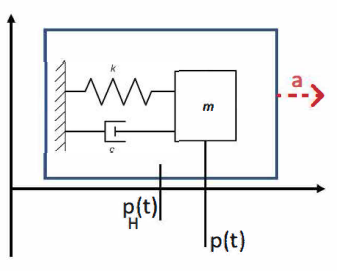
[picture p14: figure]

L’accelerometro è formato da un sistema massa-molla-smorzatore dove.

- p è la posizione della massa m
- p_H è la posizione dell’alloggiamento dell’accelerometro
- δp=p-p_H è la posizione relativa della massa rispetto alla scatola
- k è la rigidità della molla
- c è la costante di smorzamento
- a è l’accelerazione dell’alloggiamento (non è una forza!)

Ipotizziamo di saper misurare δp .

La posizione della massa all’equilibrio è p=p_H →δp=0 .

L’obiettivo è ottenere informazioni su a come funzione di δp .

Nel sistema di riferimento centrato su p_H , per mezzo delle equazioni di Newton, l’evoluzione della posizione della massa m risulta essere:

p=-k/mδp-c/mδp

Ricordando che δp=p-p_H → p=δp+p_H → p=δp+p_H , allora:

δp=-k/mδp-c/mδp-p_H → dato che a=p_H → δp=-k/mδp-c/mδp-a

Risulta che δp può essere visto come l'uscita di un sistema dinamico forzato dall'accelerazione a .

Partendo da δp=-k/mδp-c/mδp-a e applicando la trasformata di Laplace otteniamo:

∆_p (s)=-1/(s^2 +c/ms+k/m)A(s)

Di conseguenza,

- se a=costante=a , allora limt→∞δ_p (t)=-m/ka
- se a=a_1 +a_2 , la misura δ_p sarà associata ad a , cioè al valore combinato di a_1 e a_2 , ma non fornisce alcuna informazione specifica sui singoli valori di a_1 o a_2 .

Se una forza F è applicata all’alloggiamento dell’accelerometro, allora:

δp=-k/mδp-c/mδp-a+1/mF

∆_p (s)=-1/(s^2 +c/ms+k/m)((F(s))/m-A(s))

F=costante=F, a=costante=a→limt→+∞δ_p (t)=m/k(F/m-a)

Se l’accelerometro è in caduta senza forze esterne, allora:

- a=g perché il corpo cade secondo l’accelerazione gravitazionale
- F=mg perché la forza gravitazionale è applicata al corpo
- limt→+∞δ_p (t)=-m/k(F/m-a)=0

#### Elettronica

Analizziamo sensori MEMS perché sono quelli più diffusi.

(Fonte: tesi di Michele Murgia)

I dispositivi MEMS, ovvero Micro – Electro – Mechanical Systems, sono sistemi elettro-meccanici miniaturizzati ottenuti tramite processi di microfabbricazione. Questi dispositivi integrano circuiti microelettronici, strutture, attuatori e sensori, che convertono energia da una forma all'altra. I sistemi MEMS sono utilizzati per raccogliere, memorizzare, processare e scambiare informazioni per il controllo e il monitoraggio dell'ambiente esterno, offrendo dimensioni ridotte, prestazioni elevate e costi unitari bassi grazie ai processi di produzione simili a quelli dell'industria dei circuiti integrati.

Esistono diverse tipologie di accelerometri, ma sono tutte riconducibili al sistema massa – molla – smorzatore visto in precedenza.

Accelerometri capacitivi

Gli accelerometri capacitivi sono dispositivi sensori che misurano l'accelerazione utilizzando un piccolo condensatore. In questo tipo di accelerometri, una delle piastre del condensatore è solidale all'involucro dello strumento, mentre l'altra si muove rispetto alla prima grazie a un elemento elastico. La piastra mobile funge da massa inerziale, e la misura dell'accelerazione avviene valutando lo spostamento di questa massa.

Tale spostamento si ottiene da … [qui le formule varie]

Accelerometri estensimetrici

Gli accelerometri estensimetrici sono dispositivi sensori che misurano l'accelerazione attraverso la variazione di resistenza di un estensimetro, un sensore che cambia la sua resistenza in risposta a deformazioni meccaniche. In questi accelerometri, l'estensimetro è posizionato in punti strategici dove si verifica la massima deformazione a causa dell'accelerazione. Quando l'accelerometro subisce un'accelerazione, la deformazione meccanica provoca una variazione nella resistenza dell'estensimetro, permettendo di misurare l'accelerazione applicata.

Accelerometri piezoelettrici

Gli accelerometri piezoelettrici sono dispositivi sensori che sfruttano materiali piezoelettrici per misurare l'accelerazione. Questi materiali generano una tensione elettrica proporzionale alla forza applicata quando vengono sottoposti a uno sforzo meccanico. Nei accelerometri piezoelettrici, la forza dell'accelerazione viene convertita in un segnale elettrico attraverso la variazione della polarizzazione interna del materiale piezoelettrico, consentendo la misurazione dell'accelerazione.

Accelerometri magnetici

Gli accelerometri magnetici sono dispositivi sensori che utilizzano un'asta connessa a una massa mobile che può muoversi all'interno di una bobina. Il movimento della massa mobile è misurato attraverso variazioni nell'induttanza della bobina o utilizzando un sensore a effetto Hall. Questi accelerometri sfruttano il campo magnetico per rilevare l'accelerazione e sono caratterizzati da una struttura che include una molla per contrastare il movimento della massa mobile.

Accelerometri termici convettivi

Gli accelerometri termici convettivi sono sensori che sfruttano la variazione di temperatura causata da una forza fluidica o da una parte mobile all'interno di un sistema fluido per misurare l'accelerazione. Questi accelerometri valutano l'accelerazione termicamente, utilizzando il cambiamento di temperatura in un punto fisso del sistema disturbato come indicatore dell'accelerazione applicata. Sono dispositivi robusti che possono sopportare forti urti poiché non hanno parti meccaniche mobili all'interno.

Altri tipi di accelerometri

- Accelerometri a effetto tunnel: Sfruttano l'effetto tunnel quantistico tra due conduttori per misurare l'accelerazione tramite variazioni nella corrente tunnel, sensibile alla distanza tra i conduttori, offrendo una sensibilità elevata e una facile integrazione con sistemi digitali.
- Accelerometri risonanti: Utilizzano elementi vibranti in condizioni di risonanza per rilevare l'accelerazione attraverso variazioni nella frequenza di risonanza, garantendo una misurazione precisa e affidabile.
- Accelerometri ottici: Sfruttano la modulazione dell'intensità luminosa o l'interferometria per misurare l'accelerazione con elevata linearità, risoluzione e immunità al rumore elettromagnetico.

### Magnetometro

Un magnetometro è un dispositivo che misura il campo magnetico o il momento di dipolo magnetico. Diversi tipi di magnetometri misurano la direzione, la forza o il cambiamento relativo di un campo magnetico in una posizione particolare. Una bussola è uno di questi dispositivi, che misura la direzione di un campo magnetico ambientale, in questo caso, il campo magnetico terrestre.

Il magnetometro misura il campo magnetico che agisce sul sensore stesso

La Terra funziona come un gigantesco dipolo magnetico inclinato rispetto all'asse di rotazione terrestre:

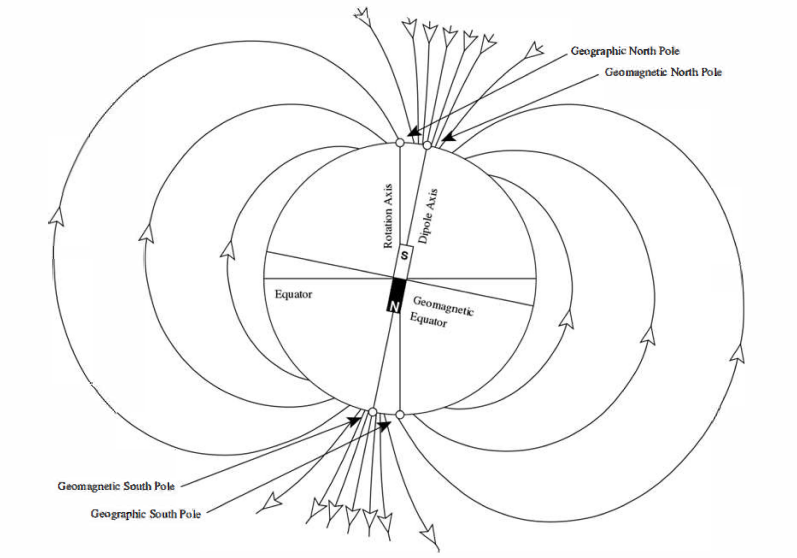
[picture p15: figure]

Il campo magnetico sulla Terra è un vettore m_0 (lat, lon, alt)∈R^3 localmente costante e tabulato/calcolato mediante modelli matematici opportunamente definiti per la superficie terrestre. Vedere https://www.ngdc.noaa.gov/geomag/calculators/magcalc.shtml#igrfwmm

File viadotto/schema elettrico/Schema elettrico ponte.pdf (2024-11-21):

PWR GND SIG -12Vcc +12Vcc LED PRESENZA TENSIONE 5Vcc

SCL LM2596 DC-DC - - + + Convertitore 12Vcc-5Vcc Simula terremoto Abbassa pilone di destra (R) Abbassa pilone centrale (C) Abbassa pilone di sinistra (L) RESET Abbassa pilone di destra (R) Simula terremoto destra (R) Simula terremoto centro (C) Simula terremoto sinistra (S) Abbassa pilone centrale (C) Abbassa pilone di sinistra (L) GND GND GND GND +5Vcc +12Vcc

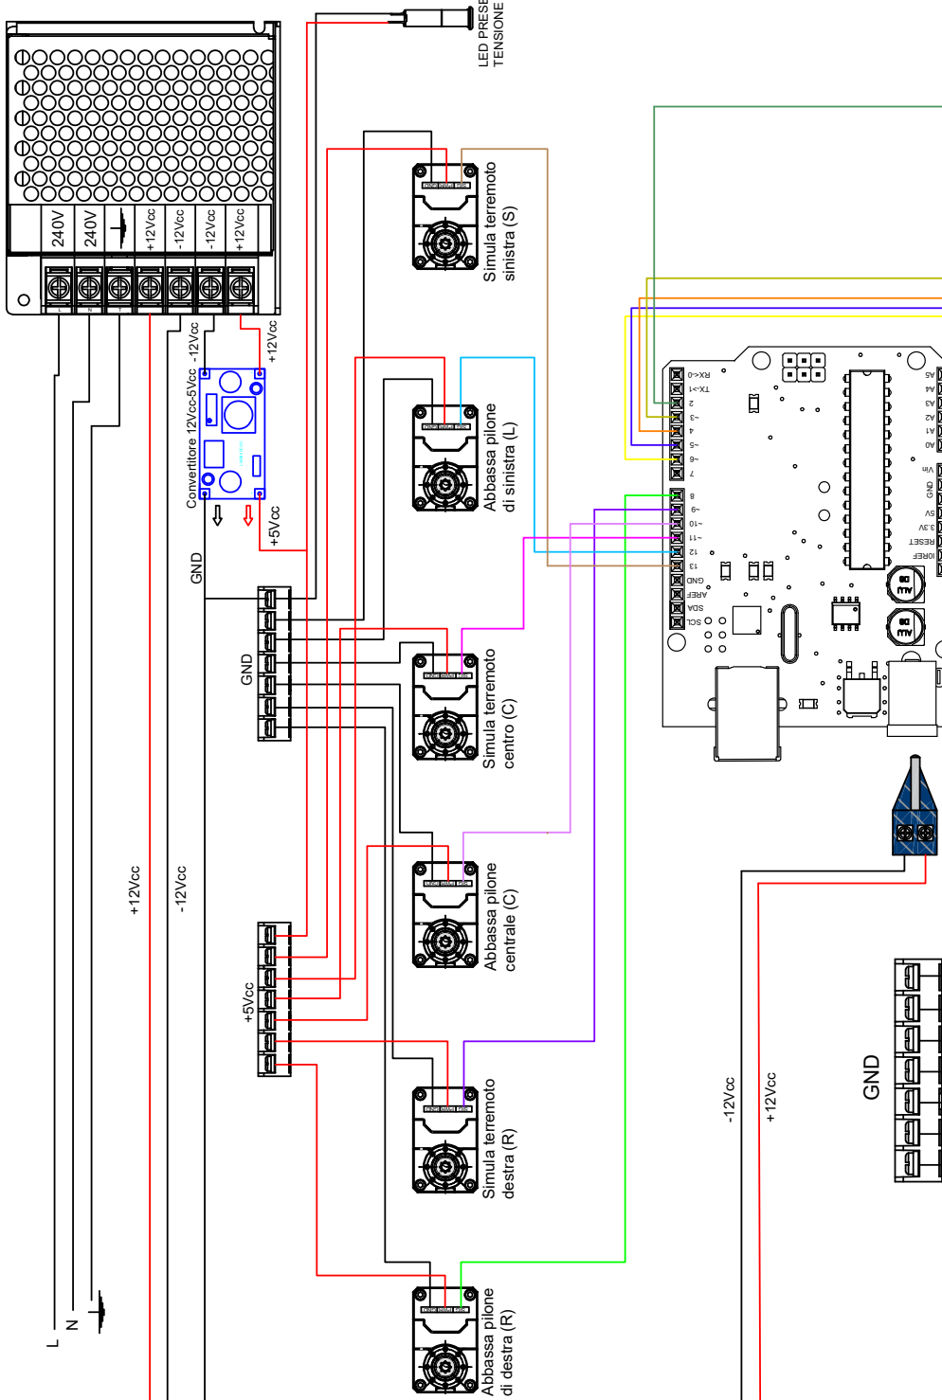
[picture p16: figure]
PWR GND SIG; GND SIG PWR GND SIG PWR; SIG PWR GND; A5A4A3A2A1A0Vin; 3.3V RESET GND; 13 GND; AREF8; I0REF SDA; +5Vcc 240V; -12Vcc +12Vcc; -12Vcc; +12Vcc 240V; +12Vcc

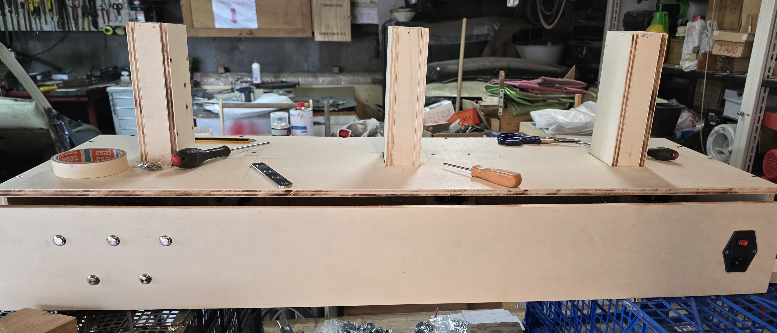
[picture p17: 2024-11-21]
viadotto/immagini e video/base e piloni.jpg

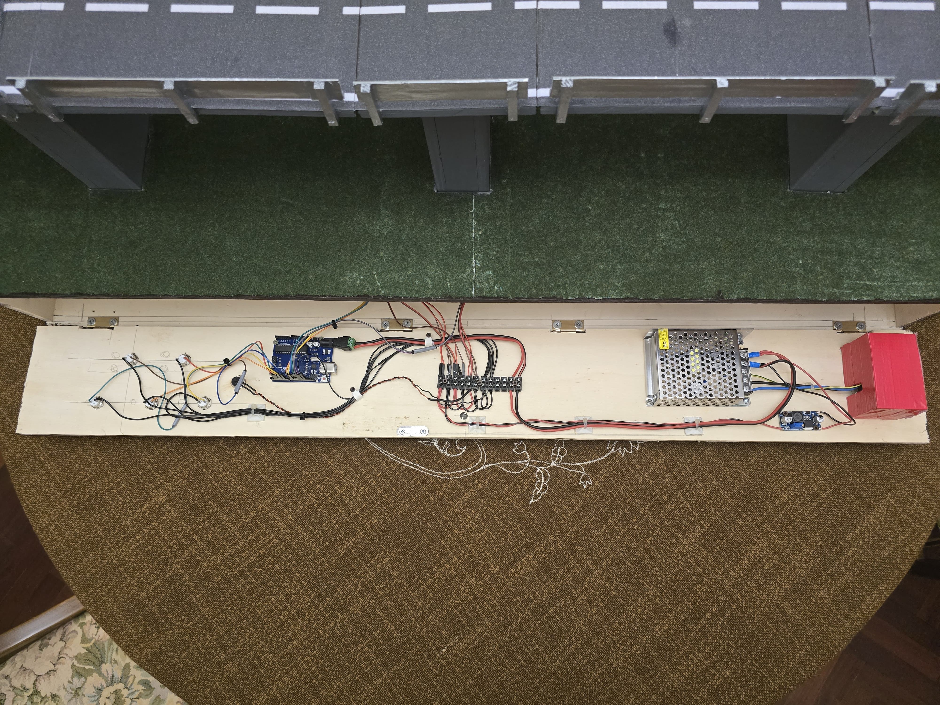
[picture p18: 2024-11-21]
viadotto/immagini e video/elettronica.jpg

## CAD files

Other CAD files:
viadotto/schema elettrico/Schema elettrico ponte.dwg

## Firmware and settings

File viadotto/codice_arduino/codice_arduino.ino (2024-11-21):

#include <Servo.h>

/* --- VARIABLES AND CONSTANTS --- */

// Servomotors initialization
Servo servoVerticalRight;
Servo servoVerticalCenter;
Servo servoVerticalLeft;
Servo servoHorizontalRight;
Servo servoHorizontalCenter;
Servo servoHorizontalLeft;

// Buttons pins
const int pinButtonHeartquake = 2;
const int pinButtonVerticalRight = 3;
const int pinButtonVerticalCenter = 4;
const int pinButtonVerticalLeft = 5;
const int pinButtonCenter = 6;

// Servomotors pins
const int pinServoVerticalRight = 8;
const int pinServoVerticalCenter = 10;
const int pinServoVerticalLeft = 12;
const int pinServoHorizontalRight = 9;
const int pinServoHorizontalCenter = 11;
const int pinServoHorizontalLeft = 13;

// Calibration of servomotors
const int initialStateVerticalRight = 90;
const int initialStateVerticalCenter = 90;
const int initialStateVerticalLeft = 90;
const int initialStateHorizontalRight = 99;
const int initialStateHorizontalCenter = 101;
const int initialStateHorizontalLeft = 97;

// Servo Motor Stress Index
const int servoStressIndex = 7;

// It is used to trigger the relaxation of the servos only
// once after the earthquake
int triggerRelaxAfterHeartquake = 0;

// Movement limits
const int maxVertical = 30;
const int minVertical = -30;
const int maxHorizontal = 13;
const int minHorizontal = -13;

// Button states
bool statusButtonHeartquake = false;
bool statusButtonVerticalRight = false;
bool statusButtonVerticalCenter = false;
bool statusButtonVerticalLeft = false;
bool statusButtonCenter = false;


/* --- UTILITY FUNCTIONS --- */

/**
 * Move the servo to a target position slowly, avoiding strain.
 * 
 * @param servo The servo motor to be controlled.
 * @param target The target angle to move the servo to.
 */
void writeSlowly(Servo& servo, int target) {
  int initialValue = servo.read();

  if (initialValue > target) {
    for (int i = initialValue; i > target; i--) {
      servo.write(i);
      delay(20);
    }
  } else {
    if (initialValue != target) {
      for (int i = initialValue; i < target + servoStressIndex; i++) {
        servo.write(i);
        delay(20);
      }
      delay(200);
      servo.write(target);
    }
  }
}  //writeSlowly

/**
 * Starts heartquake
 */
void startHeartquake() {
  servoHorizontalRight.write(initialStateHorizontalRight + maxHorizontal);
  servoHorizontalCenter.write(initialStateHorizontalCenter + maxHorizontal);
  servoHorizontalLeft.write(initialStateHorizontalLeft + maxHorizontal);
  delay(100);
  servoHorizontalRight.write(initialStateHorizontalRight + minHorizontal);
  servoHorizontalCenter.write(initialStateHorizontalCenter + minHorizontal);
  servoHorizontalLeft.write(initialStateHorizontalLeft + minHorizontal);
  delay(100);
}  //startHeartquake

/**
 * Center the servos along the x-axis
 */
void centerHorizontally() {
  servoHorizontalRight.write(initialStateHorizontalRight);
  servoHorizontalCenter.write(initialStateHorizontalCenter);
  servoHorizontalLeft.write(initialStateHorizontalLeft);
}  //centerHorizontally

/**
 * Center the servos along the y-axis
 */
void centerVertically() {
  writeSlowly(servoVerticalRight, initialStateVerticalRight);
  writeSlowly(servoVerticalCenter, initialStateVerticalCenter);
  writeSlowly(servoVerticalLeft, initialStateVerticalLeft);
}  //centerVertically

/**
 * Relaxes the servos to avoid strain after stopping the earthquake.
 */
void relaxServos() {
  servoVerticalRight.write(servoVerticalRight.read() - 2);
  writeSlowly(servoVerticalRight, servoVerticalRight.read() + 2);
  servoVerticalCenter.write(servoVerticalCenter.read() - 2);
  writeSlowly(servoVerticalCenter, servoVerticalCenter.read() + 2);
  servoVerticalLeft.write(servoVerticalLeft.read() - 2);
  writeSlowly(servoVerticalLeft, servoVerticalLeft.read() + 2);
}  //relaxServos


/* --- BUTTONS MANAGEMENT FUNCTIONS --- */

/**
 * Toggles the status of a button-controlled servo and moves it to the target position.
 * 
 * @param pin The pin number associated with the button.
 * @param status The current status of the button (true or false).
 * @param servo The servo motor to control.
 * @param initialState The initial position of the servo.
 */
void handleButton(int pin, bool& status, Servo& servo, int initialState) {
  if (statusButtonCenter == false) {
    if (digitalRead(pin) == LOW) {
      status = !status;
      delay(50);  // Debounce delay
    }

    if (status == true) {
      writeSlowly(servo, initialState + minVertical);  // Collapse position
    } else {
      writeSlowly(servo, initialState + maxVertical);  // Raised position
    }
  }
}  //handleButton

/**
 * Start/stop earthquake
 */
void handleButtonHeartquake() {
  if (statusButtonCenter == false) {
    if (digitalRead(pinButtonHeartquake) == LOW) {
      statusButtonHeartquake = !statusButtonHeartquake;
      delay(200);  // Debounce delay
    }

    if (statusButtonHeartquake == true) {
      startHeartquake();
      triggerRelaxAfterHeartquake = 0;
    } else {
      centerHorizontally();
      triggerRelaxAfterHeartquake = triggerRelaxAfterHeartquake + 1;
      if (triggerRelaxAfterHeartquake == 1) {
        relaxServos();
        if (triggerRelaxAfterHeartquake >= 200) {
          triggerRelaxAfterHeartquake = 50;
        }
      }
    }
  }
}  //handleButtonHeartquake

/**
 * Centers/resets both horizontal and vertical servos when 
 * the corresponding button is pressed
 */
void handleButtonCenter() {
  if (digitalRead(pinButtonCenter) == LOW) {
    statusButtonCenter = !statusButtonCenter;
    delay(50);  // Debounce delay
  }

  if (statusButtonCenter == true) {
    centerHorizontally();
    centerVertically();
  }
}  //handleButtonCenter


/* --- SETUP AND LOOP --- */

void setup() {
  // Attaching the servo motors to the corresponding pins
  servoVerticalRight.attach(pinServoVerticalRight);
  servoVerticalCenter.attach(pinServoVerticalCenter);
  servoVerticalLeft.attach(pinServoVerticalLeft);
  servoHorizontalRight.attach(pinServoHorizontalRight);
  servoHorizontalCenter.attach(pinServoHorizontalCenter);
  servoHorizontalLeft.attach(pinServoHorizontalLeft);

  // Setting up buttons with internal pull-up resistors
  pinMode(pinButtonVerticalRight, INPUT_PULLUP);
  pinMode(pinButtonVerticalCenter, INPUT_PULLUP);
  pinMode(pinButtonVerticalLeft, INPUT_PULLUP);
  pinMode(pinButtonCenter, INPUT_PULLUP);
  pinMode(pinButtonHeartquake, INPUT_PULLUP);

  // Initial positions
  int vGap = maxVertical + servoStressIndex;
  servoVerticalRight.write(initialStateVerticalRight + vGap);
  servoVerticalCenter.write(initialStateVerticalCenter + vGap);
  servoVerticalLeft.write(initialStateVerticalLeft + vGap);
  servoHorizontalRight.write(initialStateHorizontalRight);
  servoHorizontalCenter.write(initialStateHorizontalCenter);
  servoHorizontalLeft.write(initialStateHorizontalLeft);
  delay(200);

  Serial.begin(9600);
}  //setup

void loop() {
  handleButton(pinButtonVerticalRight, statusButtonVerticalRight, servoVerticalRight, initialStateVerticalRight);
  handleButton(pinButtonVerticalCenter, statusButtonVerticalCenter, servoVerticalCenter, initialStateVerticalCenter);
  handleButton(pinButtonVerticalLeft, statusButtonVerticalLeft, servoVerticalLeft, initialStateVerticalLeft);

  handleButtonCenter();
  handleButtonHeartquake();
}  //loop
